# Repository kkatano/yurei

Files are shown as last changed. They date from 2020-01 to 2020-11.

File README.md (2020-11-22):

# Yurei
A Tenkeyless PCB inspired by Phantom

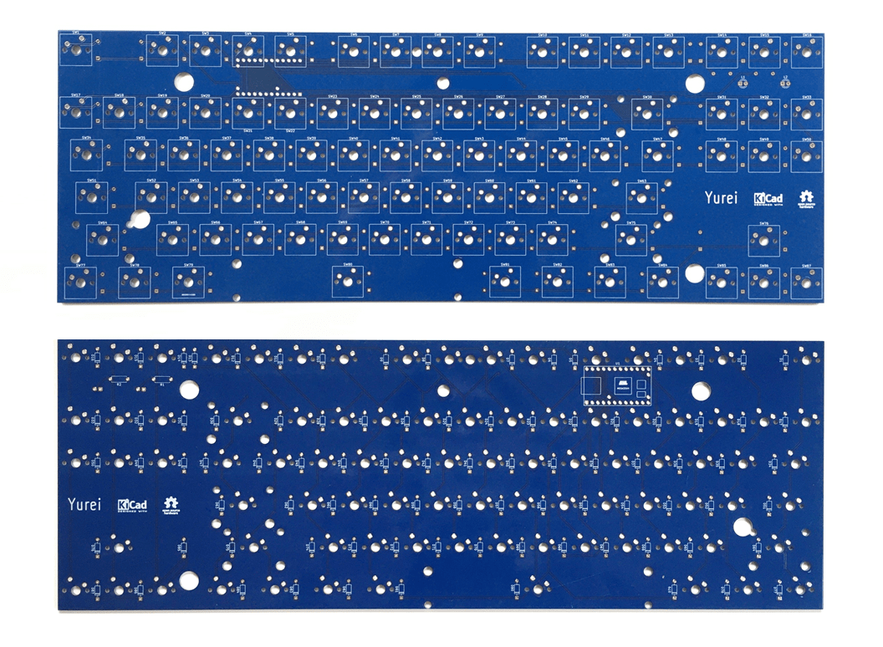
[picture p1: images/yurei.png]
yurei


## Features
 * QMK Firmware
 * Teensy 2.0 controller
 * Minimal layout support
 * No switch LEDs and no underglow
 * All switches are south facing
 * Compatible with Filco Majestouch 2 case
 * Designed with KiCAD 5.1.4

## Supported Layouts
 * ANSI

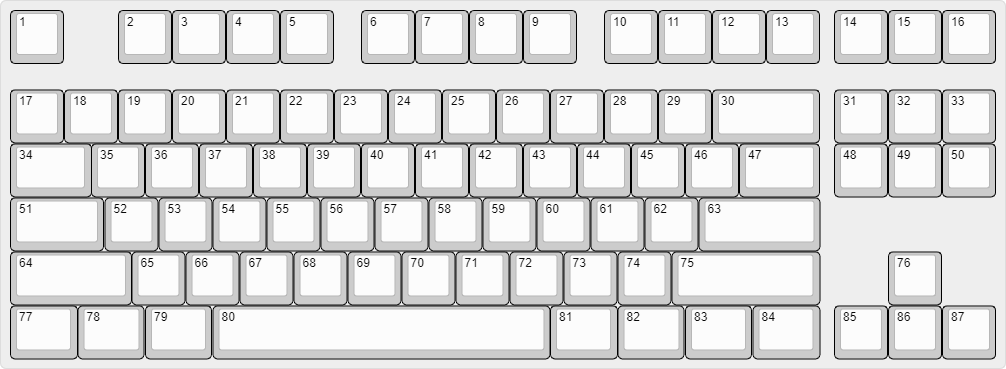
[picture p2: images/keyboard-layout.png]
keyboard-layout
 

## Supported Switches
 * Cherry MX and Cherry MX style switches

## Supported Cases
 * Filco Majestouch 2

### Note
 * [A bit modification to Filco case](images/bottom-case-mod.png) is required to install the USB cable.
 * Some other keyboard cases may also be compatible, but they have not been tested.
 * [YMDK aluminum case is not compatible](images/filco-pcb-and-ymdk-case-problem.pdf) (almost good but plate and pcb are slightly too thick, so that it causes a gap between the top and bottom cases).
   * Genuine filco PCBs and phantom PCBs also have the same problem.
   * I'm designing a new concept PCB named [Wallaby](https://github.com/kkatano/wallaby) to solve this problem. 

## BOM

| Reference | Description | Value |URL | Qty | 
|---|---|---|---|-----|
| D1-D87 | Diode | 1N4148 |https://www.digikey.jp/product-detail/en/on-semiconductor/1N4148/1N4148FS-ND/458603 | 87  | 
| L1, L2 | LED | LED |https://www.digikey.jp/product-detail/en/vishay-semiconductor-opto-division/VLHW4100/751-1502-ND/2403143 | 2 | 
| R1, R2 | Resistor | 10k |https://www.digikey.jp/product-detail/en/yageo/MFR-25FBF52-10K/10.0KXBK-ND/13219 | 2 | 
| SW1-SW87  | Key switch  | Cherry MX | | 87  | 
| U1 | Controller  | Teensy2.0 |https://www.pjrc.com/store/teensy.html | 1 | 

You also need following parts to build keyboard.

 * [LED spacer](https://www.digikey.jp/product-detail/en/keystone-electronics/7362/36-7362-ND/316720)
   * 2 pieces
 * Stabilizers
   * 4 x 2u and 1 x 6.25u
 * Plate
 * Case
 * USB mini-B cable

## Firmware

https://github.com/qmk/qmk_firmware/tree/master/keyboards/yurei

## Lisence

Yurei is released under the MIT License.

## Credits

### [The Phantom](http://bathroomepiphanies.com/keyboards/phantom/)

Source of inspiration.

### Teensy library for KiCAD

Teensy symbol and footprint are based on XenGi's libraries released under the MIT license.

#### [teensy_library](https://github.com/XenGi/teensy_library)

Copyright (c) 2015 Ricardo Band  
https://github.com/XenGi/teensy_library/blob/master/LICENSE 

#### [teensy.pretty](https://github.com/XenGi/teensy.pretty)

Copyright (c) 2015 Ricardo Band  
https://github.com/XenGi/teensy.pretty/blob/master/LICENSE

### [KiCad Libraries](https://kicad-pcb.org/libraries/)

All symbols and footprints except Teensy are based on The KiCad libraries.

### [Keyboard Layouter Plugin](https://github.com/yskoht/keyboard-layouter)

Handy plugin to place the switches.

### [keyboard-layout-editor.com](http://www.keyboard-layout-editor.com/)

Used to generate keyboard layout data to be input to Keyboard Layouter.

### [FreeRouting](https://freerouting.org/)

Good starting point for routing.

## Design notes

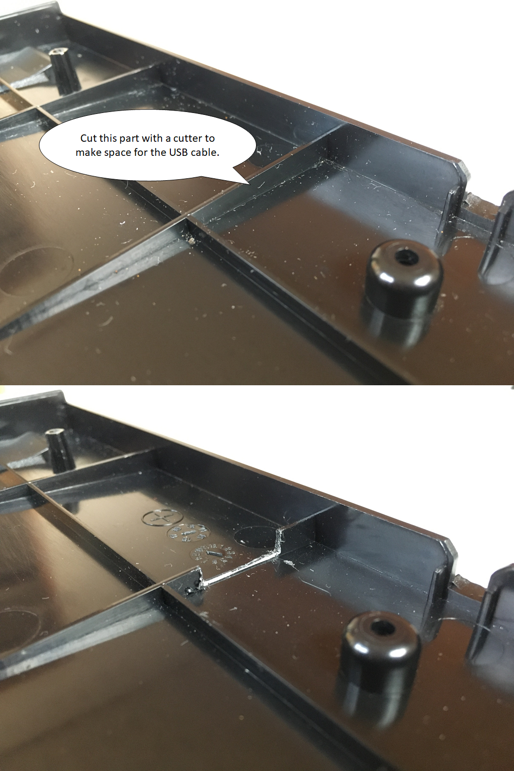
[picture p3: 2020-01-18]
images/bottom-case-mod.png

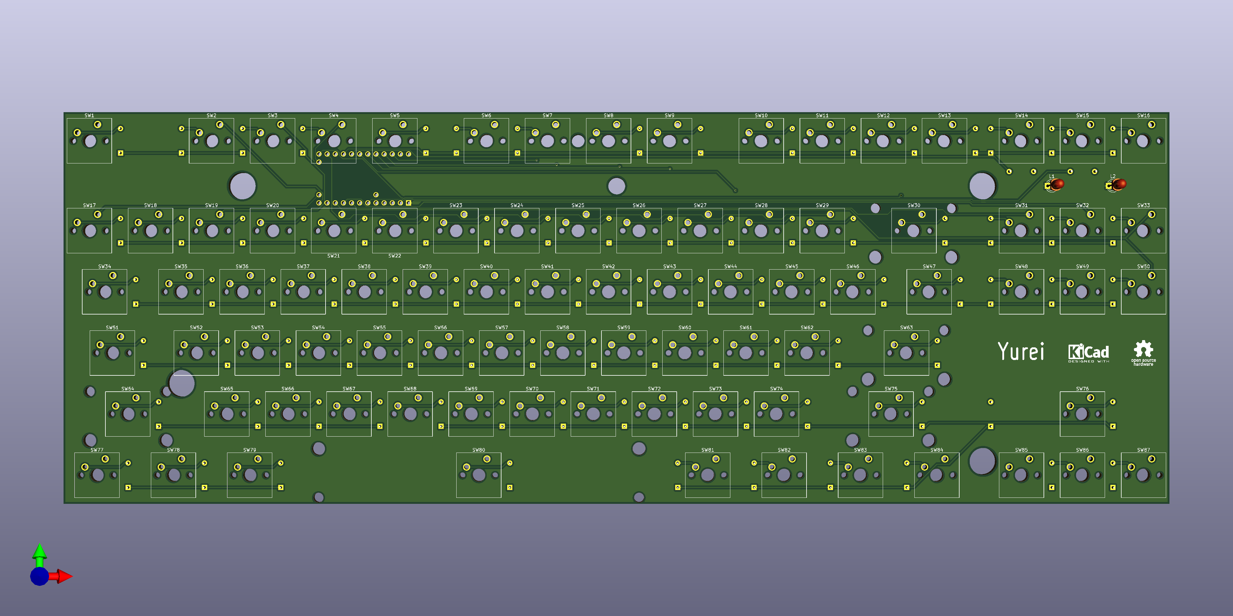
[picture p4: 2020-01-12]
images/yurei-3d.png

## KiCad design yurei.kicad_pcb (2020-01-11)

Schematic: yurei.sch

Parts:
D1, D2, D3, D4, D5, D6, D7, D8, D9, D10, D11, D12, D13, D14, D15, D16, D17, D18, D19, D20, D21, D22, D23, D24, D25, D26, D27, D28, D29, D30, D31, D32, D33, D34, D35, D36, D37, D38, D39, D40, D41, D42, D43, D44, D45, D46, D47, D48, D49, D50, D51, D52, D53, D54, D55, D56, D57, D58, D59, D60, D61, D62, D63, D64, D65, D66, D67, D68, D69, D70, D71, D72, D73, D74, D75, D76, D77, D78, D79, D80, D81, D82, D83, D84, D85, D86, D87: 1N4148; D_DO-35_SOD27_P7.62mm_Horizontal
L1, L2: LED; LED_D3.0mm
R1, R2: 10k; R_Axial_DIN0207_L6.3mm_D2.5mm_P7.62mm_Horizontal
SW1, SW2, SW3, SW4, SW5, SW6, SW7, SW8, SW9, SW10, SW11, SW12, SW13, SW14, SW15, SW16, SW17, SW18, SW19, SW20, SW21, SW22, SW23, SW24, SW25, SW26, SW27, SW28, SW29, SW31, SW32, SW33, SW35, SW36, SW37, SW38, SW39, SW40, SW41, SW42, SW43, SW44, SW45, SW46, SW48, SW49, SW50, SW52, SW53, SW54, SW55, SW56, SW57, SW58, SW59, SW60, SW61, SW62, SW65, SW66, SW67, SW68, SW69, SW70, SW71, SW72, SW73, SW74, SW76, SW85, SW86, SW87: SW_SPST; SW_Cherry_MX_1.00u_PCB
SW30: SW_SPST; SW_Cherry_MX_2.00u_PCB
SW34, SW47: SW_SPST; SW_Cherry_MX_1.50u_PCB
SW51: SW_SPST; SW_Cherry_MX_1.75u_PCB
SW63, SW64: SW_SPST; SW_Cherry_MX_2.25u_PCB
SW75: SW_SPST; SW_Cherry_MX_2.75u_PCB
SW77, SW78, SW79, SW81, SW82, SW83, SW84: SW_SPST; SW_Cherry_MX_1.25u_PCB
SW80: SW_SPST; SW_Cherry_MX_6.25u_PCB
U1: Teensy2.0_(C); Teensy2.0

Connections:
Col0: SW1.1, SW17.1, SW34.1, SW51.1, SW64.1, SW77.1, U1.13
Col1: SW2.1, SW18.1, SW35.1, SW52.1, SW78.1, U1.12
Col2: SW3.1, SW19.1, SW36.1, SW53.1, SW65.1, SW79.1, U1.11
Col3: SW4.1, SW20.1, SW37.1, SW54.1, SW66.1, U1.17
Col4: SW5.1, SW21.1, SW38.1, SW55.1, SW67.1, U1.7
Col5: SW6.1, SW22.1, SW39.1, SW56.1, SW68.1, U1.30
Col6: SW7.1, SW23.1, SW40.1, SW57.1, SW69.1, SW80.1, U1.28
Col7: SW8.1, SW24.1, SW41.1, SW58.1, SW70.1, U1.27
Col8: SW9.1, SW25.1, SW42.1, SW59.1, SW71.1, U1.26
Col9: SW10.1, SW26.1, SW43.1, SW60.1, SW72.1, U1.25
Col10: SW11.1, SW27.1, SW44.1, SW61.1, SW73.1, SW81.1, U1.24
Col11: SW12.1, SW28.1, SW45.1, SW62.1, SW74.1, SW82.1, U1.23
Col12: SW13.1, SW29.1, SW46.1, SW75.1, SW83.1, U1.19
Col13: SW30.1, SW47.1, SW63.1, SW84.1, U1.18
Col14: SW14.1, SW31.1, SW48.1, SW85.1, U1.8
Col15: SW15.1, SW32.1, SW49.1, SW76.1, SW86.1, U1.9
Col16: SW16.1, SW33.1, SW50.1, SW87.1, U1.10
GND: L1.1, L2.1, U1.1
LED1: R1.1, U1.22
LED2: R2.1, U1.6
unnamed: D1.2, SW1.2
unnamed: D2.2, SW2.2
unnamed: D3.2, SW3.2
unnamed: D4.2, SW4.2
unnamed: D5.2, SW5.2
unnamed: D6.2, SW6.2
unnamed: D7.2, SW7.2
unnamed: D8.2, SW8.2
unnamed: D9.2, SW9.2
unnamed: D10.2, SW10.2
unnamed: D11.2, SW11.2
unnamed: D12.2, SW12.2
unnamed: D13.2, SW13.2
unnamed: D14.2, SW14.2
unnamed: D15.2, SW15.2
unnamed: D16.2, SW16.2
unnamed: D17.2, SW17.2
unnamed: D18.2, SW18.2
unnamed: D19.2, SW19.2
unnamed: D20.2, SW20.2
unnamed: D21.2, SW21.2
unnamed: D22.2, SW22.2
unnamed: D23.2, SW23.2
unnamed: D24.2, SW24.2
unnamed: D25.2, SW25.2
unnamed: D26.2, SW26.2
unnamed: D27.2, SW27.2
unnamed: D28.2, SW28.2
unnamed: D29.2, SW29.2
unnamed: D30.2, SW30.2
unnamed: D31.2, SW31.2
unnamed: D32.2, SW32.2
unnamed: D33.2, SW33.2
unnamed: D34.2, SW34.2
unnamed: D35.2, SW35.2
unnamed: D36.2, SW36.2
unnamed: D37.2 (A), SW37.2
unnamed: D38.2, SW38.2
unnamed: D39.2, SW39.2
unnamed: D40.2, SW40.2
unnamed: D41.2, SW41.2
unnamed: D42.2, SW42.2
unnamed: D43.2, SW43.2
unnamed: D44.2, SW44.2
unnamed: D45.2, SW45.2
unnamed: D46.2, SW46.2
unnamed: D47.2, SW47.2
unnamed: D48.2, SW48.2
unnamed: D49.2, SW49.2
unnamed: D50.2, SW50.2
unnamed: D51.2, SW51.2
unnamed: D52.2, SW52.2
unnamed: D53.2, SW53.2
unnamed: D54.2, SW54.2
unnamed: D55.2, SW55.2
unnamed: D56.2, SW56.2
unnamed: D57.2, SW57.2
unnamed: D58.2, SW58.2
unnamed: D59.2, SW59.2
unnamed: D60.2, SW60.2
unnamed: D61.2, SW61.2
unnamed: D62.2, SW62.2
unnamed: D63.2, SW63.2
unnamed: D64.2, SW64.2
unnamed: D65.2, SW65.2
unnamed: D66.2, SW66.2
unnamed: D67.2, SW67.2
unnamed: D68.2, SW68.2
unnamed: D69.2, SW69.2
unnamed: D70.2, SW70.2
unnamed: D71.2, SW71.2
unnamed: D72.2, SW72.2
unnamed: D73.2, SW73.2
unnamed: D74.2, SW74.2
unnamed: D75.2, SW75.2
unnamed: D76.2, SW76.2
unnamed: D77.2, SW77.2
unnamed: D78.2, SW78.2
unnamed: D79.2, SW79.2
unnamed: D80.2, SW80.2
unnamed: D81.2, SW81.2
unnamed: D82.2, SW82.2
unnamed: D83.2, SW83.2
unnamed: D84.2, SW84.2
unnamed: D85.2, SW85.2
unnamed: D86.2, SW86.2
unnamed: D87.2, SW87.2
unnamed: L1.2, R1.2
unnamed: L2.2, R2.2
Row0: D1.1, D2.1, D3.1, D4.1, D5.1, D6.1, D7.1, D8.1, D9.1, D10.1, D11.1, D12.1, D13.1, D14.1, D15.1, D16.1, U1.21
Row1: D17.1, D18.1, D19.1, D20.1, D21.1, D22.1, D23.1, D24.1, D25.1, D26.1, D27.1, D28.1, D29.1, D30.1, D31.1, D32.1, D33.1, U1.20
Row2: D34.1, D35.1, D36.1, D37.1 (K), D38.1, D39.1, D40.1, D41.1, D42.1, D43.1, D44.1, D45.1, D46.1, D47.1, D48.1, D49.1, D50.1, U1.5
Row3: D51.1, D52.1, D53.1, D54.1, D55.1, D56.1, D57.1, D58.1, D59.1, D60.1, D61.1, D62.1, D63.1, U1.4
Row4: D64.1, D65.1, D66.1, D67.1, D68.1, D69.1, D70.1, D71.1, D72.1, D73.1, D74.1, D75.1, D76.1, U1.3
Row5: D77.1, D78.1, D79.1, D80.1, D81.1, D82.1, D83.1, D84.1, D85.1, D86.1, D87.1, U1.2

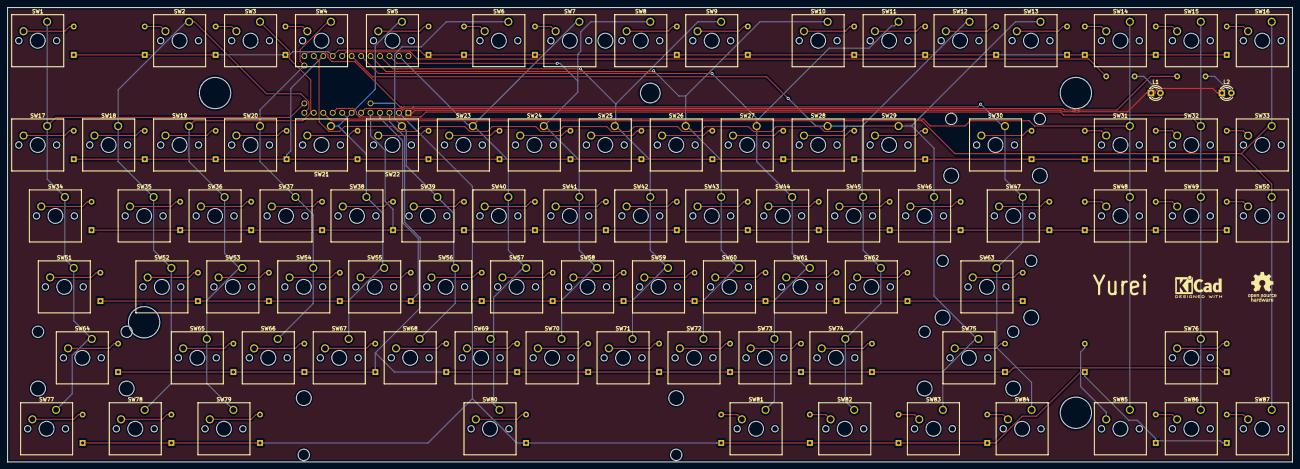
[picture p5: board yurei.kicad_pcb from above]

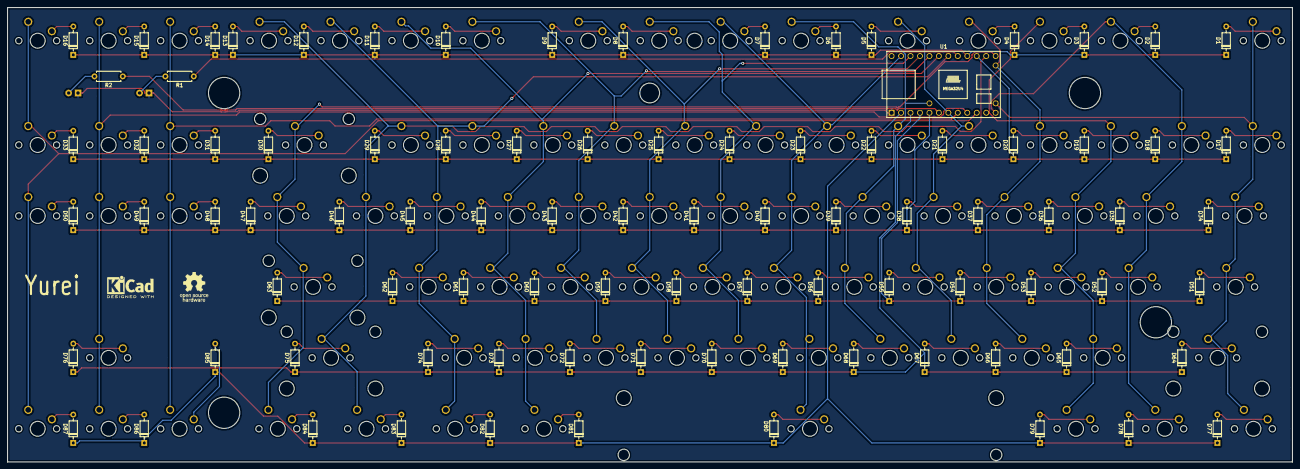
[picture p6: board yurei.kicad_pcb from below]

Board: 2 copper layers, 345.0 x 122.0 mm, 183 parts (92 on the bottom side), 115 nets.

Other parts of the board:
kicad1, kicad2: KiCad-Logo2_5mm_SilkScreen
oshw1, oshw2: OSHW-Logo_7.5x8mm_SilkScreen

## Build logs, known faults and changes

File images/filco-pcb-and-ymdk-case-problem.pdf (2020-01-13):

## Phantom/Yurei PCB

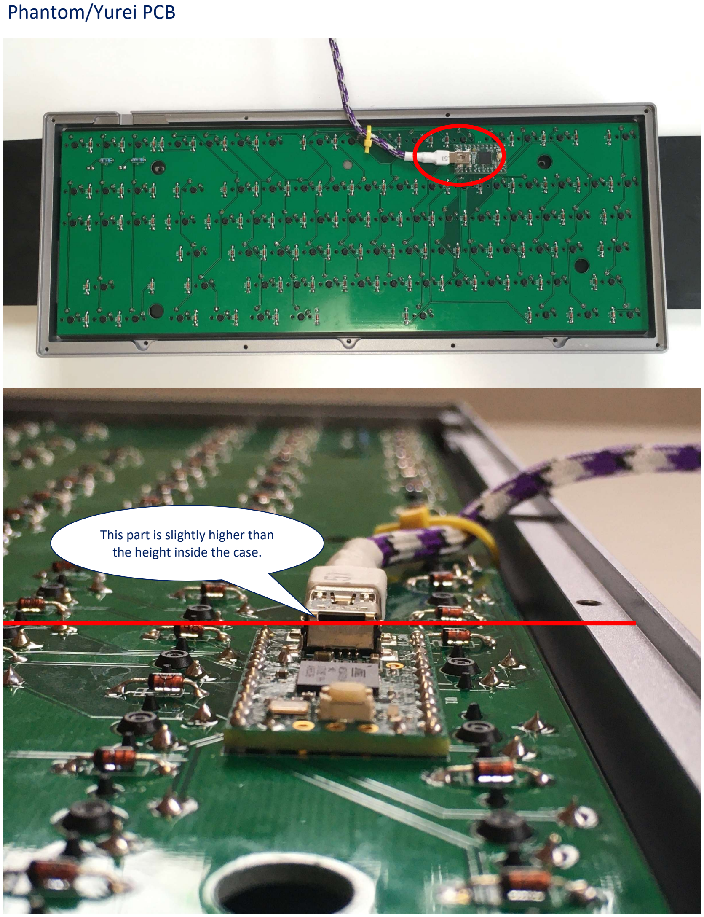
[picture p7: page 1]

This part is slightly higher than the height inside the case.

## Genuine Filco PCB

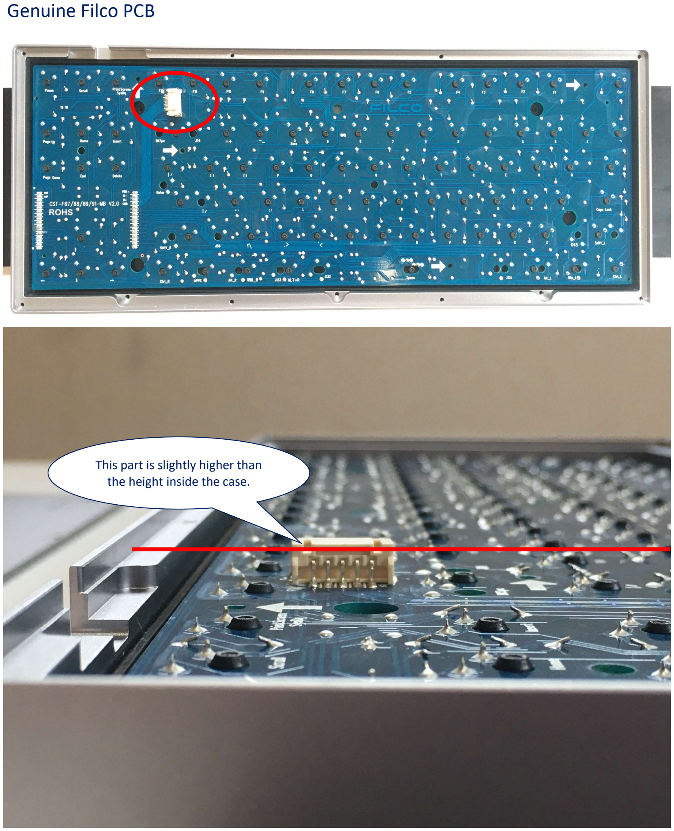
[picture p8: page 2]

This part is slightly higher than the height inside the case.

## Result

## Phantom/Yurei

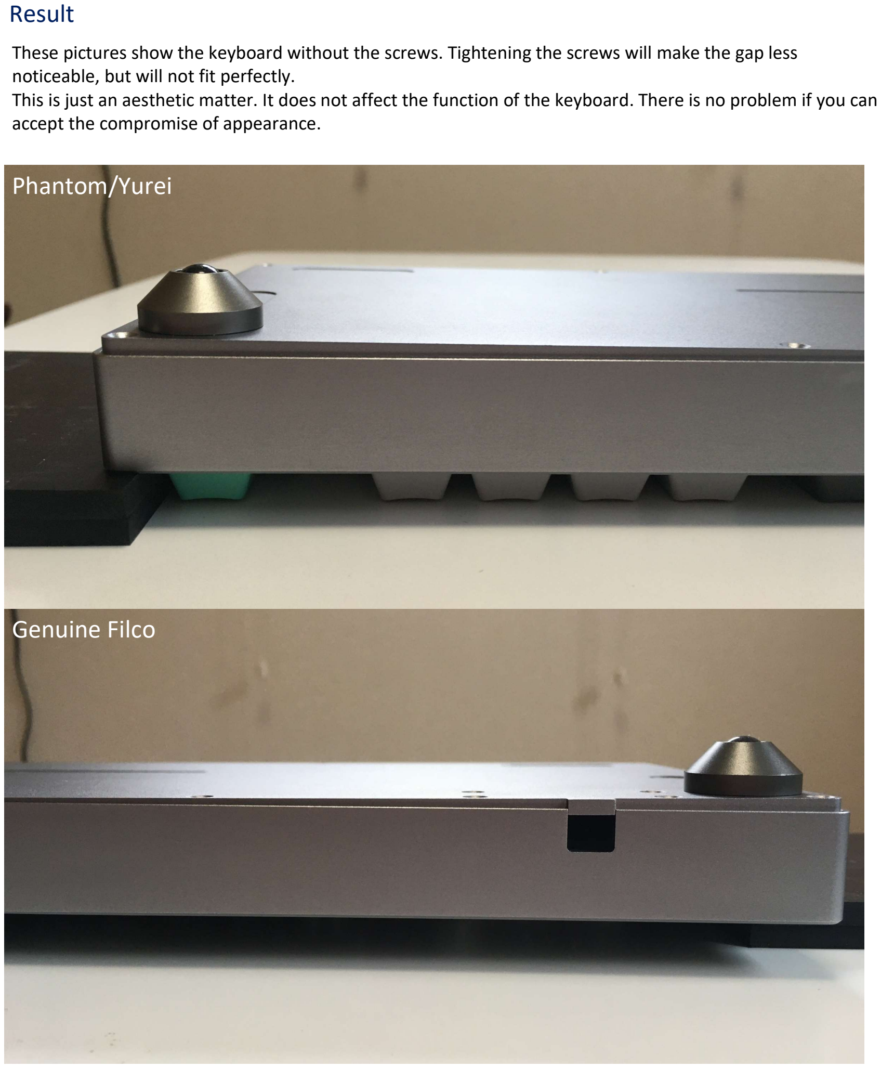
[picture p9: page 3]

These pictures show the keyboard without the screws. Tightening the screws will make the gap less noticeable, but will not fit perfectly.
This is just an aesthetic matter. It does not affect the function of the keyboard. There is no problem if you can accept the compromise of appearance.

## Genuine Filco

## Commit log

2019-11-09 Initialize project
    [yurei.kicad_pcb, yurei.sch]
2019-11-09 Add teensy library
2019-11-12 Drafting PCB
2019-11-16 Create gerber files
    [yurei-B_Cu.gbl, yurei-B_Mask.gbs, yurei-B_Paste.gbp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]
2019-11-16 Remove files to be ignored
    [yurei.dsn]
2020-01-11 Clean up
    [yurei-B_Cu.gbl, yurei-B_Mask.gbs, yurei-B_Paste.gbp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]
2020-01-11 Add logo to PCB
    [yurei.kicad_pcb]
2020-01-11 Update footprint
    [yurei.kicad_pcb]
2020-01-11 Update footprints
    [yurei.kicad_pcb]
2020-01-11 Update route
    [yurei.kicad_pcb]
2020-01-18 Update BOM
    [yurei.sch]
2020-01-18 Add case mod picture
